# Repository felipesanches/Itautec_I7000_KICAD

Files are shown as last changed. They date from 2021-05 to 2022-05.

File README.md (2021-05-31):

Trabalho de levantamento empírico dos esquemáticos do computador Itautec I-7000.

De vez em quando eu atualizo os PDFs:
- i7000.pdf (placa-mãe principal)
- i7000_disk.pdf (placa da interface de controle de disquetes)
- há também uma placa "TELEX" mas não comecei ainda a levantar o esquema dela.

Mas na maior parte do tempo estou só editando no KICAD os arquivos de esquemáticos e PCB por enquanto. Estou tentando me dedicar algumas horas todos os dias para essa tarefa...

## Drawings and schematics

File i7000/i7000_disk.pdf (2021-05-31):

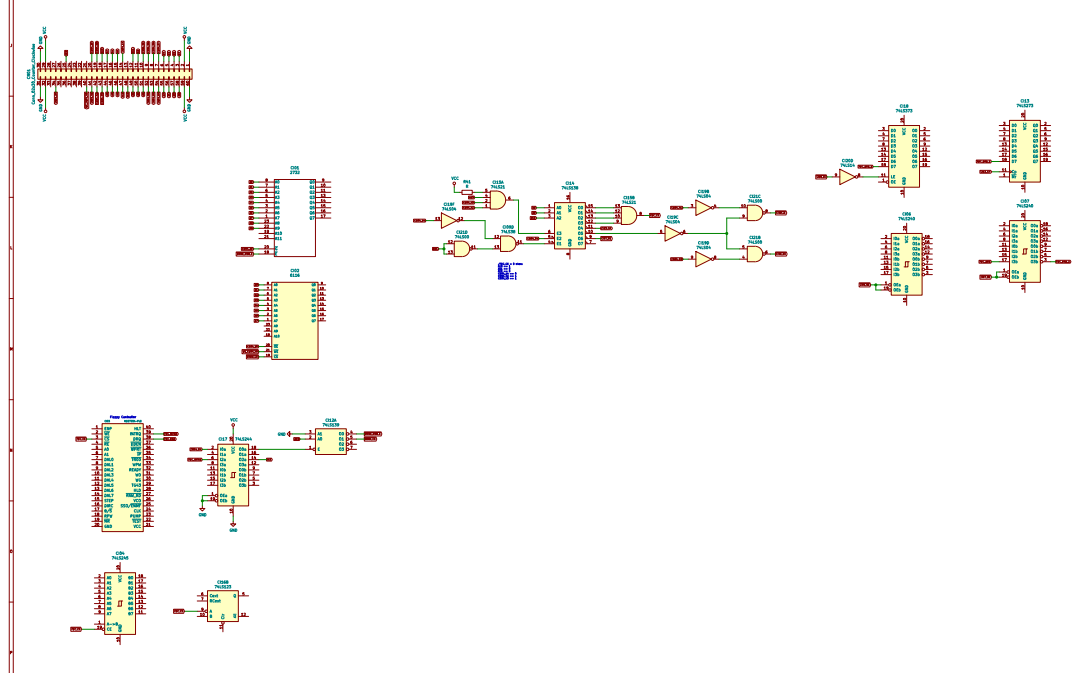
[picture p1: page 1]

1 405060 2111 314151 2212 324252 2313 334353 2414 344454 2515 354555 2616 364656 2717 374757 2818 384858 2919 394959 CN01 Conn_02x30_Counter_Clockwise A6 A7 A9 A12 A10A0A2A1 A11 A3 VCC GND VCC GND VCC GND VCC GND A13 A4A8 A5 WE_CN04_40 CN04_34 CN04_19 CN04_14 CN04_42 CN04_43 A7 1 A6 2 A5 3 A4 4 A3 5 A2 6 A1 7 A0 8 Q0 9 Q1 10 G

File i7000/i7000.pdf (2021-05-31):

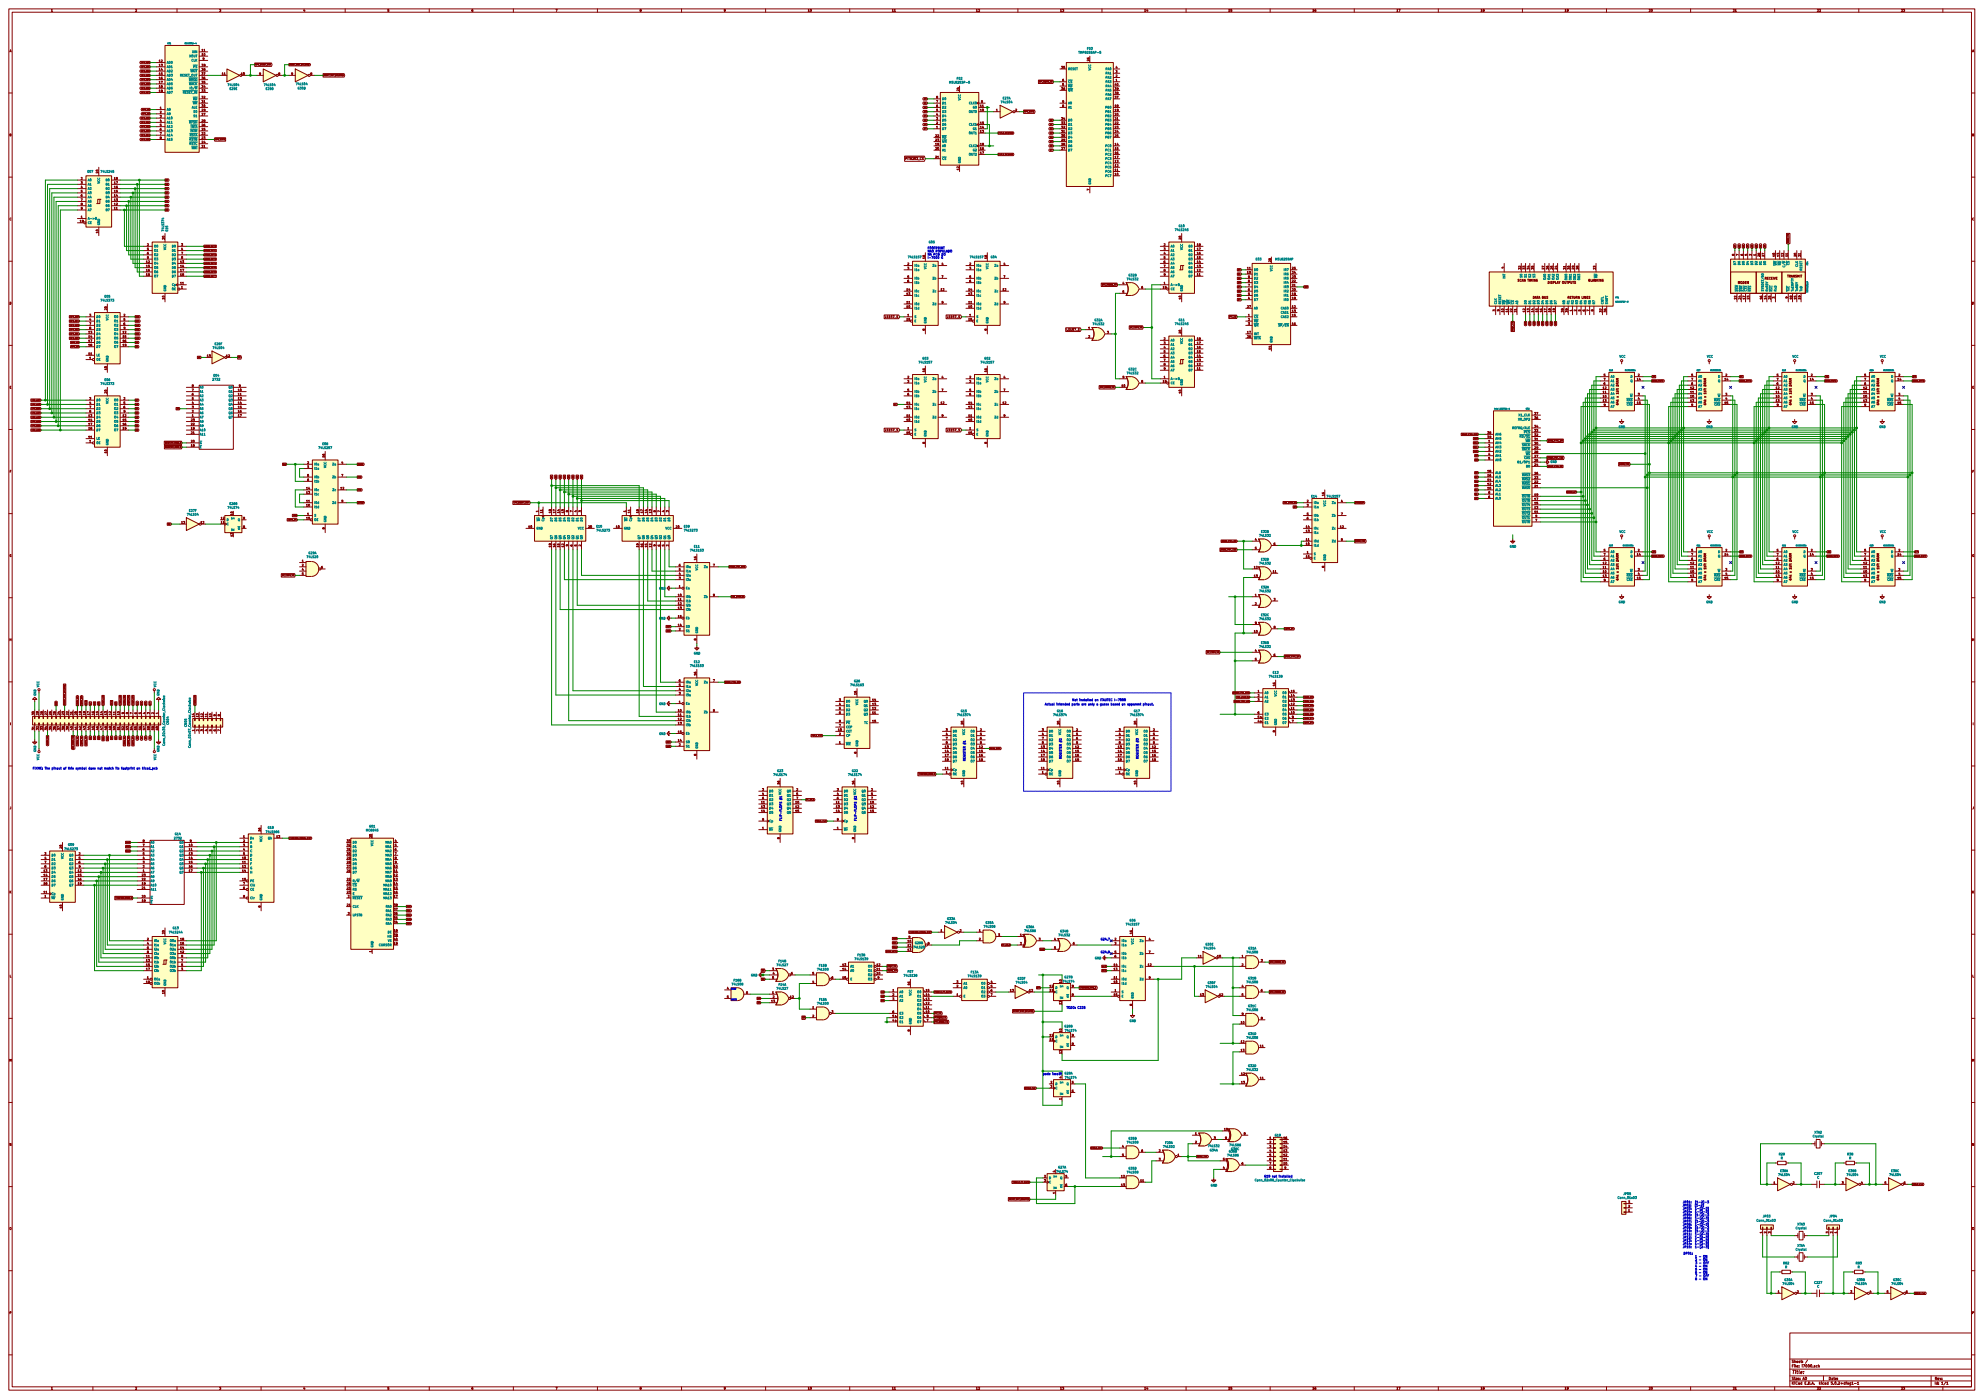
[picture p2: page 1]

DATA BUSDISPLAY OUTPUTS RETURN LINES

4 - ON 5 - ON 6 - ON 7 - OFF

Id: 1/1 Title: File: i7000.sch Sheet: /

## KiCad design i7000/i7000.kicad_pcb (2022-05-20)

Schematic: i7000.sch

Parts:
C207, C227: C; C_Disc_D3.8mm_W2.6mm_P2.50mm
CN04: Conn_02x30_Counter_Clockwise; Pin_Header_Straight_2x30_Pitch2.54mm
CN05: Conn_02x07_Counter_Clockwise; DIP-14_W7.62mm_Socket
E01: NSC800D-4; DIP-40_W15.24mm
E02: Intel D8202A-1; DIP-40_W15.24mm
E03: M5L8259AP; DIP-28_W15.24mm
E04: 2732; DIP-24_W15.24mm_Socket
E05, E06: 74LS373; DIP-20_W7.62mm
E07: 74LS245; DIP-20_W7.62mm
E08: 74LS257; DIP-16_W7.62mm
E09, E10: 74LS273; DIP-20_W7.62mm
E11, E12: 74LS153; DIP-16_W7.62mm
E13: 74LS138; DIP-16_W7.62mm
E14: 74LS157; DIP-16_W7.62mm
E15: 74LS374; DIP-20_W7.62mm
E16, E17, E18, E19, E20, E21, E22, E23: MCM6665A; DIP-16_W7.62mm
E24, E25, E26: 74LS74; DIP-14_W7.62mm
E27, E28, E29, E38: 74LS04; DIP-14_W7.62mm
E30: 74LS02; DIP-14_W7.62mm
E31, E34: 74LS08; DIP-14_W7.62mm
E32, E33, E36: 74LS32; DIP-14_W7.62mm
E35: 74LS00; DIP-14_W7.62mm
E37: SN74LS07N; DIP-14_W7.62mm
F01: M5L8279P-5; DIP-40_W15.24mm
F02: M5L8253P-5; DIP-24_W15.24mm
F03: TMP8255AP-5; DIP-40_W15.24mm
F04: TMP8251AP; DIP-28_W15.24mm
F05: ADC0808; DIP-28_W15.24mm
F06, F07: 74LS138; DIP-16_W7.62mm
F08, F11, F12: 74LS74; DIP-14_W7.62mm
F9, F10: 74LS163; DIP-16_W7.62mm
F13: 74LS139; DIP-16_W7.62mm
F14: 74LS27; DIP-14_W7.62mm
F15: 74LS00; DIP-14_W7.62mm
F16: 74LS08; DIP-14_W7.62mm
F17: MC1488; DIP-14_W7.62mm
F18, F19: MC1489; DIP-14_W7.62mm
F20: 74LS02; DIP-14_W7.62mm
F21: 74LS04; DIP-14_W7.62mm
F22, F23: SN74LS07N; DIP-14_W7.62mm
G01: MC6845; DIP-40_W15.24mm
G02, G03, G04, G05, G06: 74LS157; DIP-16_W7.62mm
G07, G08: TMM2016AP; DIP-24_W15.24mm
G09, G12: 74LS273; DIP-20_W7.62mm
G10, G11: 74LS245; DIP-20_W7.62mm
G13: 74LS244; DIP-20_W7.62mm
G14: 2732; DIP-24_W15.24mm_Socket
G15, G16, G17: 74LS374; DIP-20_W7.62mm
G18: 74LS166; DIP-16_W7.62mm
G19: Conn_02x08_Counter_Clockwise; DIP-16_W7.62mm
G20, G21: 74LS153; DIP-16_W7.62mm
G22, G23: 74LS174; DIP-16_W7.62mm
G25, G27, G28: 74LS74; DIP-14_W7.62mm
G26: 74LS163; DIP-16_W7.62mm
G29: 74LS20; DIP-14_W7.62mm
G30, G33: 74LS04; DIP-14_W7.62mm
G31, G35: 74LS08; DIP-14_W7.62mm
G32, G34: 74LS32; DIP-14_W7.62mm
G36: 74LS86; DIP-14_W7.62mm
G37: 74128; DIP-14_W7.62mm
G38, G39: 74LS00; DIP-14_W7.62mm
G40, G41: 74S140; DIP-14_W7.62mm
JP03, JP04, JP05: Conn_01x03; Pin_Header_Straight_1x03_Pitch2.54mm
R29, R38, R82, R83: R; R_Axial_DIN0207_L6.3mm_D2.5mm_P10.16mm_Horizontal
XTA2, XTA3, XTA4: Crystal; Crystal_AT310_d3.0mm_l10.0mm_Horizontal_1EP_style2

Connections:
A0: CN04.49, E02.6 (AL0), E06.19 (O7)
A1: CN04.51, E02.8 (AL1), E06.16 (O6)
A2: CN04.50, E02.10 (AL2), E06.15 (O5), F07.1 (A0)
A3: CN04.11, E02.12 (AL3), E06.12 (O4), F07.2 (A1)
A4: CN04.16, E02.14 (AL4), E06.9 (O3), F07.3 (A2), F14.5
A5: CN04.44, E02.16 (AL5), E04.3 (A5), E06.6 (O2), E28.13
A6: CN04.45, E02.18 (AL6), E06.5 (O1), F14.13
A7: CN04.17, E06.2 (O0), E14.3 (I1a), F14.2, G03.14 (I0c)
A8: CN04.15, E02.5 (AH0), E05.19 (O7)
A9: CN04.46, E02.4 (AH1), E05.16 (O6)
A10: CN04.48, E02.3 (AH2), E05.15 (O5)
A11: CN04.12, E02.2 (AH3), E05.12 (O4), G06.13 (I1c)
A12: CN04.47, E02.1 (AH4), E05.9 (O3)
A13: CN04.18, E02.39 (AH5), E05.6 (O2), G06.14 (I0c)
A14: E05.5 (O1), E11.14 (S0), E12.14 (S0)
A15: E05.2 (O0), E11.2 (S1), E12.2 (S1)
CHARGEN_SERIAL_OUT: G18.13 (Qh), G33.1
CN04_07: CN04.7, E13.9 (O6)
CN04_08: CN04.8, E13.10 (O5)
CN04_09: CN04.9, E13.12 (O3)
CN04_10: CN04.10, E13.14 (O1)
CN04_14: CN04.14
CN04_19: CN04.19
CN04_20: CN04.20
CN04_34: CN04.34, E08.15 (OE)
CN04_41: CN04.41
CN04_42: CN04.42
CN04_43: CN04.43
CN04_52: CN04.52, E13.13 (O2)
CN04_53: CN04.53, E13.11 (O4)
CN04_54: CN04.54, E13.7 (O7)
CN05_14: CN05.14, E32.8
CPU_A8: E01.1 (A8), E05.18 (D7)
CPU_A9: E01.2 (A9), E05.17 (D6)
CPU_A10: E01.3 (A10), E05.14 (D5)
CPU_A11: E01.4 (A11), E05.13 (D4)
CPU_A12: E01.5 (A12), E05.8 (D3)
CPU_A13: E01.6 (A13), E05.7 (D2)
CPU_A14: E01.7 (A14), E05.4 (D1)
CPU_A15: E01.8 (A15), E05.3 (D0)
CPU_AD0: E01.12 (AD0), E06.18 (D7), E07.9 (A7)
CPU_AD1: E01.13 (AD1), E06.17 (D6), E07.8 (A6)
CPU_AD2: E01.14 (AD2), E06.14 (D5), E07.7 (A5)
CPU_AD3: E01.15 (AD3), E06.13 (D4), E07.6 (A4)
CPU_AD4: E01.16 (AD4), E06.8 (D3), E07.5 (A3)
CPU_AD5: E01.17 (AD5), E06.7 (D2), E07.4 (A2)
CPU_AD6: E01.18 (AD6), E06.4 (D1), E07.3 (A1)
CPU_AD7: E01.19 (AD7), E06.3 (D0), E07.2 (A0)
D0: CN04.57, E03.11 (D0), E07.11 (B7), E09.3 (D0), E10.3 (D0), E15.2 (O0), E16.2 (D), F01.12 (D0), F02.8 (D0), F03.34 (D0), F04.27 (D0), G27.12 (D)
D1: CN04.56, E03.10 (D1), E07.12 (B6), E09.4 (D1), E10.4 (D1), E15.5 (O1), E17.2 (D), F01.13 (D1), F02.7 (D1), F03.33 (D1), F04.28 (D1)
D2: CN04.5, E03.9 (D2), E07.13 (B5), E09.7 (D2), E10.7 (D2), E15.6 (O2), E18.2 (D), F01.14 (D2), F02.6 (D2), F03.32 (D2), F04.1 (D2)
D3: CN04.55, E03.8 (D3), E07.14 (B4), E09.8 (D3), E10.8 (D3), E15.9 (O3), E19.2 (D), F01.15 (D3), F02.5 (D3), F03.31 (D3), F04.2 (D3)
D4: CN04.6, E03.7 (D4), E07.15 (B3), E09.13 (D4), E10.13 (D4), E15.12 (O4), E20.2 (D), F01.16 (D4), F02.4 (D4), F03.30 (D4), F04.5 (D4)
D5: CN04.4, E03.6 (D5), E07.16 (B2), E09.14 (D5), E10.14 (D5), E15.15 (O5), E21.2 (D), F01.17 (D5), F02.3 (D5), F03.29 (D5), F04.6 (D5)
D6: CN04.58, E03.5 (D6), E07.17 (B1), E09.17 (D6), E10.17 (D6), E15.16 (O6), E22.2 (D), F01.18 (D6), F02.2 (D6), F03.28 (D6), F04.7 (D6)
D7: CN04.3, E03.4 (D7), E07.18 (B0), E09.18 (D7), E10.18 (D7), E15.19 (O7), E23.2 (D), F01.19 (D7), F02.1 (D7), F03.27 (D7), F04.8 (D7)
DRAM_A7: E14.4 (Za), E16.9 (A7), E17.9 (A7), E18.9 (A7), E19.9 (A7), E20.9 (A7), E21.9 (A7), E22.9 (A7), E23.9 (A7)
DRAM_CTRL_AH6: E02.38 (AH6), E11.7 (Za), E13.1 (A0)
DRAM_CTRL_B0: E02.24 (B0), E12.7 (Za), E13.3 (A2), E32.4, E32.12
DRAM_OUT0: E15.3 (D0), E16.14 (Q)
DRAM_OUT1: E15.4 (D1), E17.14 (Q)
DRAM_OUT2: E15.7 (D2), E18.14 (Q)
DRAM_OUT3: E15.8 (D3), E19.14 (Q)
DRAM_OUT4: E15.13 (D4), E20.14 (Q)
DRAM_OUT5: E15.14 (D5), E21.14 (Q)
DRAM_OUT6: E15.17 (D6), E22.14 (Q)
DRAM_OUT7: E15.18 (D7), E23.14 (Q)
E11_pin9_Zb: E11.9 (Zb), E13.2 (A1), E14.2 (I0a)
E38.6_CLK: E38.6
F20.1_CLK: F20.1, G22.9 (Cp), G26.2 (CP), G34.2, G36.5
FF_23.2: G23.7 (Q2), G36.2
G30.6_CLK: G28.3 (C), G30.6, G35.4
GND: CN04.1, CN04.30, CN04.31, CN04.60, E01.20 (GND), E02.20 (GND), E02.25 (B1/OP1), E04.12 (GND), E11.1 (Ea), E11.8 (GND), E11.15 (Eb), E12.1 (Ea), E12.15 (Eb), E16.16 (GND), E17.16 (GND), E18.16 (GND), E19.16 (GND), E20.16 (GND), E21.16 (GND), E22.16 (GND), E23.16 (GND), F01.20 (GND), F04.4 (GND), F14.4, G06.6 (I1b), G06.8 (GND), G07.12 (GND), G08.12 (GND), G14.12 (GND), G36.4, G37.7 (GND)
Gnd: G40.7 (Gnd), G41.7 (Gnd)
IOM: E08.1 (S)
IOR: E08.7 (Zb)
IOW: E08.12 (Zc)
IR3: CN04.25, E03.21 (IR3)
LS157_S: G02.1 (S), G03.1 (S), G04.1 (S), G05.1 (S), G32.1
MEMR: E08.4 (Za)
MEMW: E08.9 (Zd)
unnamed: C207.1, E38.3, R38.2
unnamed: C207.2, E38.2, R29.1
unnamed: C227.1, G30.3, JP04.2, R83.2
unnamed: C227.2, G30.2, R82.1
unnamed: E01.37 (RESET_OUT), E29.11
unnamed: E02.7 (~OUT0), E16.5 (A0), E17.5 (A0), E18.5 (A0), E19.5 (A0), E20.5 (A0), E21.5 (A0), E22.5 (A0), E23.5 (A0)
unnamed: E02.9 (~OUT1), E16.7 (A1), E17.7 (A1), E18.7 (A1), E19.7 (A1), E20.7 (A1), E21.7 (A1), E22.7 (A1), E23.7 (A1)
unnamed: E02.11 (~OUT2), E16.6 (A2), E17.6 (A2), E18.6 (A2), E19.6 (A2), E20.6 (A2), E21.6 (A2), E22.6 (A2), E23.6 (A2)
unnamed: E02.13 (~OUT3), E16.12 (A3), E17.12 (A3), E18.12 (A3), E19.12 (A3), E20.12 (A3), E21.12 (A3), E22.12 (A3), E23.12 (A3)
unnamed: E02.15 (~OUT4), E16.11 (A4), E17.11 (A4), E18.11 (A4), E19.11 (A4), E20.11 (A4), E21.11 (A4), E22.11 (A4), E23.11 (A4)
unnamed: E02.17 (~OUT5), E16.10 (A5), E17.10 (A5), E18.10 (A5), E19.10 (A5), E20.10 (A5), E21.10 (A5), E22.10 (A5), E23.10 (A5)
unnamed: E02.19 (~OUT6), E16.13 (A6), E17.13 (A6), E18.13 (A6), E19.13 (A6), E20.13 (A6), E21.13 (A6), E22.13 (A6), E23.13 (A6)
unnamed: E02.21 (~RAS0), E16.4 (~RAS), E17.4 (~RAS), E18.4 (~RAS), E19.4 (~RAS), E20.4 (~RAS), E21.4 (~RAS), E22.4 (~RAS), E23.4 (~RAS)
unnamed: E02.28 (~WE), E16.3 (~W), E17.3 (~W), E18.3 (~W), E19.3 (~W), E20.3 (~W), E21.3 (~W), E22.3 (~W), E23.3 (~W)
unnamed: E08.3 (I1a), E08.5 (I0b)
unnamed: E08.10 (I1d), E08.14 (I0c)
unnamed: E08.11 (I0d), E08.13 (I1c)
unnamed: E09.2 (Q0), E11.6 (I0a)
unnamed: E09.5 (Q1), E11.10 (I0b)
unnamed: E09.6 (Q2), E12.6 (I0a)
unnamed: E09.9 (Q3), E12.10 (I0b)
unnamed: E09.12 (Q4), E11.5 (I1a)
unnamed: E09.15 (Q5), E11.11 (I1b)
unnamed: E09.16 (Q6), E12.5 (I1a)
unnamed: E09.19 (Q7), E12.11 (I1b)
unnamed: E10.2 (Q0), E11.4 (I2a)
unnamed: E10.5 (Q1), E11.12 (I2b)
unnamed: E10.6 (Q2), E12.4 (I2a)
unnamed: E10.9 (Q3), E12.12 (I2b)
unnamed: E10.12 (Q4), E11.3 (I3a)
unnamed: E10.15 (Q5), E11.13 (I3b)
unnamed: E10.16 (Q6), E12.3 (I3a)
unnamed: E10.19 (Q7), E12.13 (I3b)
unnamed: E13.6 (E3), E32.10, E32.13, E36.5
unnamed: E14.10 (I1d), E14.11 (I0d), E32.6
unnamed: E26.11 (C), E27.12
unnamed: E27.1, F02.10 (OUT0)
unnamed: E32.1, E32.9
unnamed: E38.1, R29.2, XTA2.1
unnamed: E38.4, E38.5, R38.1, XTA2.2
unnamed: F02.11 (G0), F02.14 (G1)
unnamed: F02.13 (OUT1), F17.9
unnamed: F02.15 (CLK1), F02.18 (CLK2)
unnamed: F02.17 (OUT2), F17.2
unnamed: F07.4 (E1), F07.5 (E2)
unnamed: F07.6 (E3), F15.3
unnamed: F07.14 (O1), F13.1 (E)
unnamed: F13.6 (O2), G33.13
unnamed: F13.15 (E), F15.6
unnamed: F14.1, F16.6
unnamed: F14.6, F15.5
unnamed: F14.12, F15.1, F15.4
unnamed: F20.2, G35.6
unnamed: F20.3, G35.11
unnamed: G06.3 (I1a), G34.6
unnamed: G06.9 (Zd), G28.13 (~R), G30.11
unnamed: G06.12 (Zc), G30.13, G31.2
unnamed: G06.15 (E), G27.8 (~Q)
unnamed: G09.2 (Q0), G13.2 (I0a), G14.5 (A3)
unnamed: G09.5 (Q1), G13.4 (I1a), G14.4 (A4)
unnamed: G09.6 (Q2), G13.6 (I2a), G14.3 (A5)
unnamed: G09.9 (Q3), G13.8 (I3a), G14.2 (A6)
unnamed: G09.12 (Q4), G13.11 (I0b), G14.1 (A7)
unnamed: G09.15 (Q5), G13.13 (I1b), G14.23 (A8)
unnamed: G09.16 (Q6), G13.15 (I2b), G14.22 (A9)
unnamed: G09.19 (Q7), G13.17 (I3b), G14.19 (A10)
unnamed: G10.19 (CE), G32.6
unnamed: G11.19 (CE), G32.8
unnamed: G13.3 (O3b), G14.17 (Q7), G18.14 (H)
unnamed: G13.5 (O2b), G14.16 (Q6), G18.12 (G)
unnamed: G13.7 (O1b), G14.15 (Q5), G18.11 (F)
unnamed: G13.9 (O0b), G14.14 (Q4), G18.10 (E)
unnamed: G13.12 (O3a), G14.13 (Q3), G18.5 (D)
unnamed: G13.14 (O2a), G14.11 (Q2), G18.4 (C)
unnamed: G13.16 (O1a), G14.10 (Q1), G18.3 (B)
unnamed: G13.18 (O0a), G14.9 (Q0), G18.2 (A)
unnamed: G19.7, G36.6
unnamed: G27.2 (D), G27.6 (~Q), G35.13
unnamed: G27.10 (~S), G28.1 (~R), G28.4 (~S), G28.10 (~S), G28.12 (D)
unnamed: G27.11 (C), G33.12
unnamed: G28.5 (Q), G35.12
unnamed: G29.8, G35.2
unnamed: G30.1, JP03.2, R82.2
unnamed: G30.4, G30.5, R83.1
unnamed: G30.10, G31.1, G31.4, G31.9
unnamed: G30.12, G31.5
unnamed: G31.10, G31.12
unnamed: G31.13, G32.13
unnamed: G32.3, G32.5, G32.9
unnamed: G33.2, G35.1
unnamed: G34.3, G36.9
unnamed: G34.4, G36.3
unnamed: G35.3, G36.1
unnamed: G35.5, G36.10
unnamed: JP03.1, XTA4.2
unnamed: JP03.3, XTA3.2
unnamed: JP04.1, XTA4.1
unnamed: JP04.3, XTA3.1
RA0: G01.38 (RA0), G14.8 (A0), G29.9
RA1: G01.37 (RA1), G14.7 (A1), G29.10
RA2: G01.36 (RA2), G14.6 (A2), G29.12
RA3: G01.35 (RA3), G34.5
RA4: G01.34 (RA4)
RD: E08.2 (I0a), E08.6 (I1b), E27.13
REG1_BIT4: G15.12 (O4), G29.13
RESET_OUT_DELAYED: CN04.23, E29.8, G30.9
TOGGLE_FF_G27A: F07.15 (O0), G27.3 (C)
VCC: CN04.2, CN04.29, CN04.32, CN04.59, E01.40 (VCC), E02.40 (VCC), E16.8 (VCC), E17.8 (VCC), E18.8 (VCC), E19.8 (VCC), E20.8 (VCC), E21.8 (VCC), E22.8 (VCC), E23.8 (VCC), F01.40 (VCC), F04.26 (VCC), G07.24 (VCC), G08.24 (VCC), G37.14 (VCC)
Vcc: E04.24 (Vcc), G14.24 (Vcc), G40.14 (Vcc), G41.14 (Vcc)
~A5: E28.12, F14.3, F15.2
~CHARGEN_ROM_G: G14.20 (~G), G15.1 (OE), G27.9 (Q)
~CPU_RESET_OUT: E09.1 (~Mr), E10.1 (~Mr), E29.9, E29.10
~CPU_RSTB: E01.23 (~RSTB), E27.2
~DRAM_CAS: E14.9 (Zd), E16.15 (~CAS), E17.15 (~CAS), E18.15 (~CAS), E19.15 (~CAS), E20.15 (~CAS), E21.15 (~CAS), E22.15 (~CAS), E23.15 (~CAS)
~DRAM_CTRL_CAS: E02.27 (~CAS), E32.5
~DRAM_CTRL_WR: E02.31 (~WR), E36.6
~GFX_SRAM1_CS: G31.3, G32.4
~GFX_SRAM2_CS: G31.6, G32.10
~I8251_CS: F04.11 (~CS), F13.11 (O1)
~KBDC_CS: F01.22 (~CS), F13.12 (O0)
~MAINCPU_ROM_E: E04.18 (~E)
~MAINCPU_ROM_G: E04.20 (~G)
~PIC_CS: E03.1 (~CS~), F07.10 (O5)
~PIT8253_CS: F02.21 (~CS~), F07.9 (O6)
~PPI_I8255_CS: F03.6 (~CS~), F07.7 (O7)
~RESET_OUT_DELAYED: G27.1 (~R), G27.13 (~R), G30.8
~WE_CN04_40: CN04.40, E36.4, G10.1 (A->B), G11.1 (A->B), G29.5

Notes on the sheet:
READ
WRITE
FOOTPRINT NAO POPULADO NA PCB DO I-7000 G
G24.7
G24.9
FIXME: The pinout of this symbol does not match its footprint on kicad_pcb
TODO: C225
pode isso?!
REGISTER #1
FLIP-FLOPS #1
Not installed on ITAUTEC I-7000
Actual intended parts are only a guess based on apparent pinout.
REGISTER #2
REGISTER #3
G19 not installed
FLIP-FLOPS #2
JP01: [1-2]-3 JP02: [1-2] JP03: 1-[2-3] JP04: 1-[2-3] JP05: [1-2]-3 JP06: 1-[2-3] JP07: [1-2]-3 JP08: 1-[2-3] JP09: [1-2]-3 JP10: [1-2]-3 JP11: 1-[2-3] JP12: 1-[2-3] JP13: 1-[2-3] JP14: 1-[2-3] JP15: 1-[2-3] DP01: 1 - ON 2 - ON 3 - OFF 4 - ON 5 - ON 6 - ON 7 - OFF 8 - ON
8-Bit μP Compatible A/D Converters with 8-Channel Multiplexer

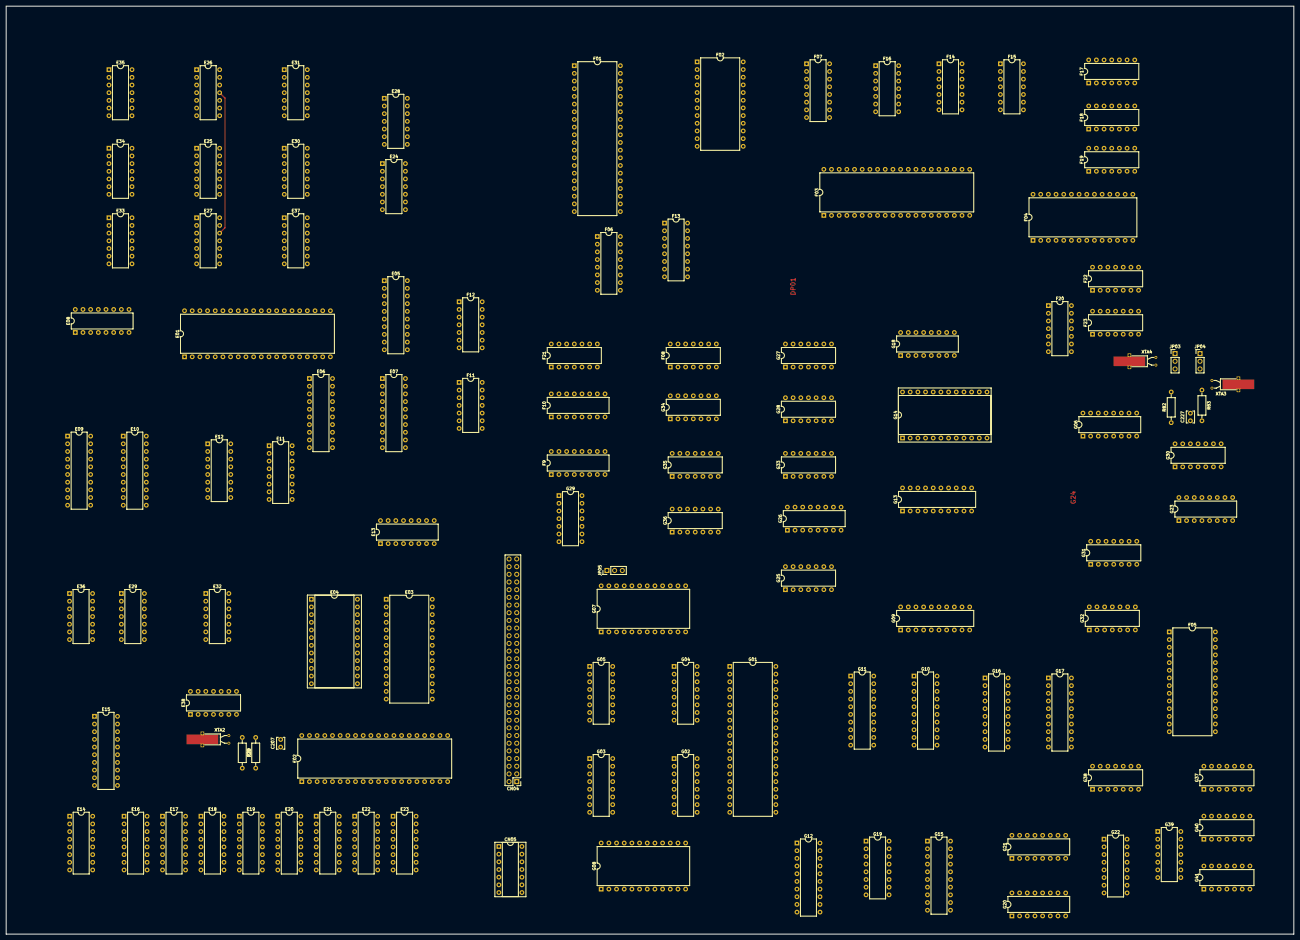
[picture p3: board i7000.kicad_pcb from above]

Board: 2 copper layers, 426.0 x 307.0 mm, 115 parts (0 on the bottom side), 193 nets.

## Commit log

2020-11-16 esboco inicial dos esquematicos de algumas partes do circuito do I7000
    [i7000.kicad_pcb, i7000.sch]
2020-11-19 transcricao de ontem de madrugada
    [i7000.sch]
2020-11-19 mais um pouco hoje
    [i7000.sch]
2020-11-20 creating a library of symbols for chips used in the Itautec I7000 but still not available in KICAD libraries. We should contribute these later to the project.
    [i7000.sch]
2020-11-21 Mais um símbolo novo pro KICAD: Programmable Keyboard/display controler M5L8279P-5
    [i7000.sch]
2020-11-21 TMP8251AP - Programmable Communication Interface (Serial Port Controller)
    [i7000.sch]
2021-05-28 Not sure what was that, but these changes were sitting here on my local copy since the last time I worked on this schematic drawing effort. I guess it is safer to commit it separately before working 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
    [i7000.sch]
2021-05-28 anotando alguns componentes que estavam sem referencias
    [i7000.sch]
2021-05-28 splitting drawing into one schematic per PCB
    [i7000.sch, i7000_disk.sch]
2021-05-28 iniciando o posicionamento de componentes da PCB principal
    [i7000.sch]
2021-05-29 mais um pedacinho do circuito
    [i7000.sch]
2021-05-29 atualizando footprints no layout da PCB
    [i7000.kicad_pcb]
2021-05-30 avanços de ontem
    [i7000.sch]
2021-05-30 update footprints and PCB layout
    [i7000.kicad_pcb, i7000.sch]
2021-05-31 avanços de hoje ;-)
    [i7000.kicad_pcb, i7000.sch]
2021-05-31 atualizando os PDFs de esquemáticos e adicionando um "LEIAME" ;-)
2022-05-18 local modifications left on my working copy uncommitted since the last time I worked on this project... I'm blindly commiting this in the hope it is good stuff ;-) (crossing fingers here LOL)
2022-05-18 symbol drawing for TMM2016AP (SRAM)
    and added a few more symbols on the schematics
    [i7000.kicad_pcb]
2022-05-18 use Package_DIP footprints instead of the older ones called Housings_DIP
    [i7000.kicad_pcb, i7000.sch]
2022-05-19 a few more chips
    [i7000.kicad_pcb, i7000.sch]
2022-05-20 coloquei todos os chips no esquemático e na PCB. Agora falta "só" mapear os sinais...
    [i7000.kicad_pcb, i7000.sch]
